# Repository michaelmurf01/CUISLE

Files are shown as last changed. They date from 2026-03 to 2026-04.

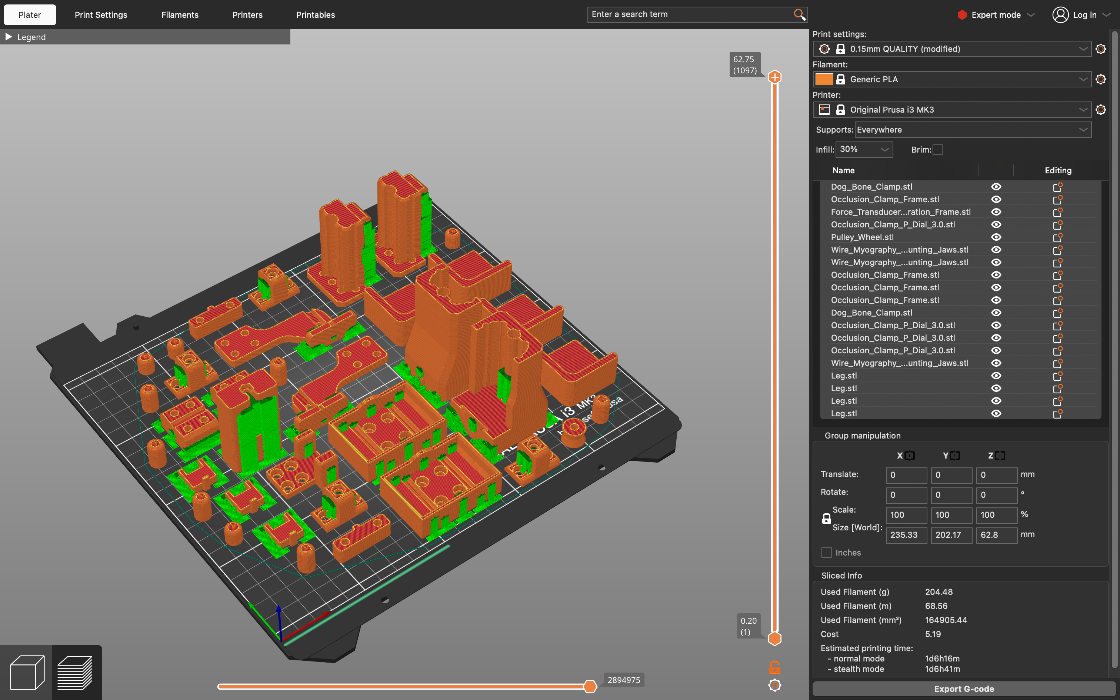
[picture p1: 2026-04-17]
Slicer_Images/All_Other_Parts_Slicer.png

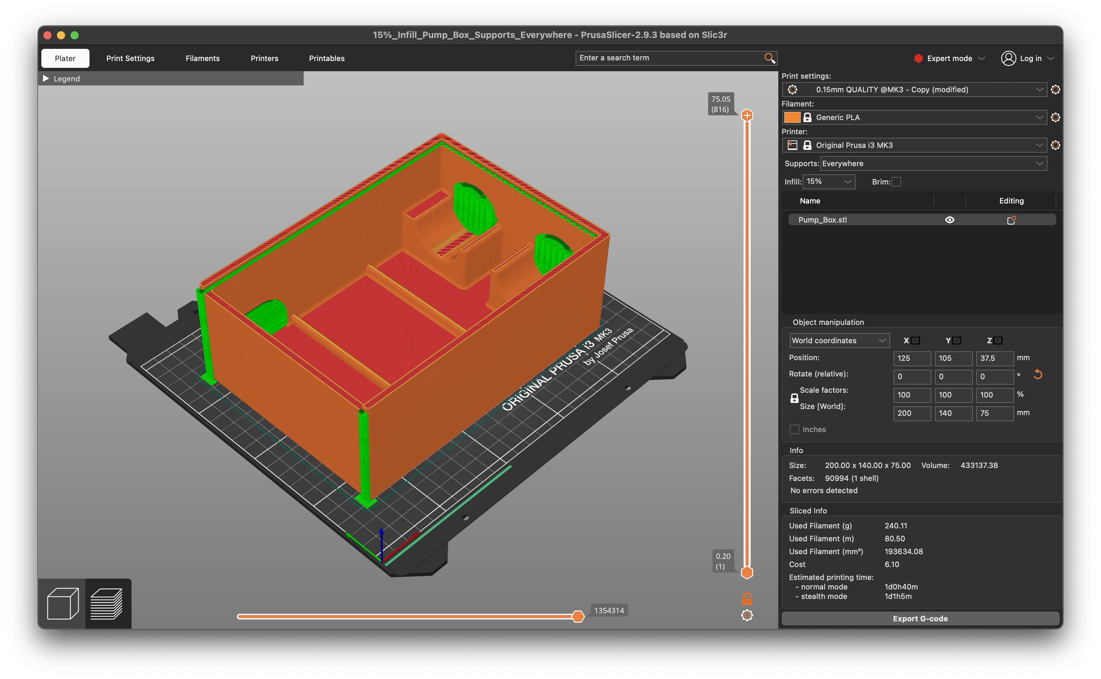
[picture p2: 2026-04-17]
Slicer_Images/Pump_Enclosure.png

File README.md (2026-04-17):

# CUISLE
### Cardiovascular Universal Instrument for Shared-source Low-cost Experimentation

*Cuisle (kwee-shla) — Irish for pulse/vein/artery*

---

A low-cost, open-source instrument for versatile vascular testing, developed at Trinity College Dublin. CUISLE supports four testing configurations — ring, wire myography, pressure myography and uniaxial — from a single multifunctional attachment, at a unit cost of €269.38 (inc. VAT, Ireland, March 2026).

---

## Repository Contents

| Type | Description |
|---|---|
| `/BOM` | Full Bill of Materials with component sources and costs |
| `/CAD` | All FDM printing files (.STL) for every printed module |
| `/Firmware` | Arduino IDE scripts for peristaltic pump control |

---

## Coming Soon
- 🔧 Step-by-step assembly and operating instructions

---

## Developed By
Michael William Murphy
supervised by Prof. Brooke Tornifoglio
Department of Mechanical, Manufacturing & Biomedical Engineering, Trinity College Dublin

---

## Licence
This project is open-source. If you use CUISLE in your research, please cite accordingly.

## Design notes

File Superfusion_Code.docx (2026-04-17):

SUPERFUSION CODE

#include <Servo.h>

// ─── CONFIG ───────────────────────────────────────────

// Direction: FORWARD or REVERSE

// Speed: 0 (fastest) to 89 (slowest, just before stop)

#define PUMP1_DIRECTION FORWARD // FORWARD

#define PUMP1_SPEED 20 // 20

#define PUMP2_DIRECTION FORWARD // FORWARD

#define PUMP2_SPEED 0 // 0

// ──────────────────────────────────────────────────────

#define FORWARD 1

#define REVERSE 0

Servo pump1;

Servo pump2;

#define PUMP1_PIN 9

#define PUMP2_PIN 10

int getAngle(int direction, int speed) {

// speed 0 = fastest, 89 = slowest

speed = constrain(speed, 0, 89);

if (direction == FORWARD) {

return speed; // 0–89 (0 = max forward)

} else {

return 180 - speed; // 180–91 (180 = max reverse)

}

}

void setup() {

pump1.attach(PUMP1_PIN);

pump2.attach(PUMP2_PIN);

pump1.write(90); // stop on startup

pump2.write(90);

delay(1000);

pump1.write(getAngle(PUMP1_DIRECTION, PUMP1_SPEED));

pump2.write(getAngle(PUMP2_DIRECTION, PUMP2_SPEED));

}

void loop() {

// Nothing needed — pumps run at fixed setting

}

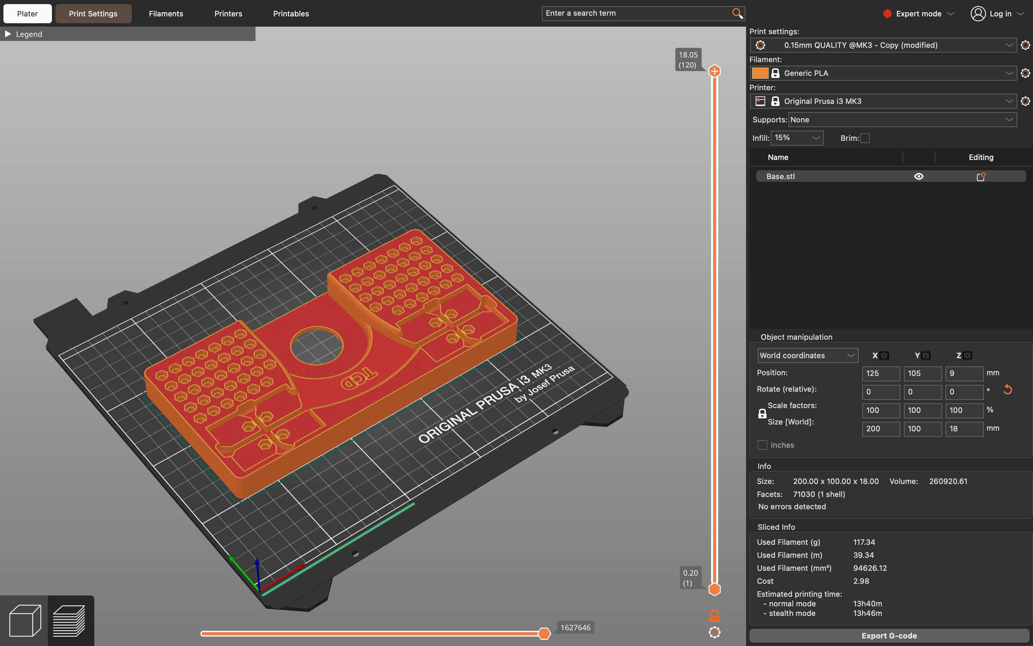
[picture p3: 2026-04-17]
Slicer_Images/Base_Slicer.png

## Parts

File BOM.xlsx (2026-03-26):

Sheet: Final BOM
Assembly Name | X
Assembly # | 1
Assembly Revision | 2026-04-10
Date of Approval | 2026-03-10
Total Cost (€) | 364.01 |  | * INC VAT, everything listed except Additional Items
Total Cost per Unit (€) | 269.38 |  | * INC VAT, everything listed except Additional Items
Item # | Lay Des. | Mfg. | Mfg. Des. | Mfg./Sup. Part # | Link | Qty | Units | Unit Cost (€) | Cost INC VAT (€) | Legend | Des. | Unit Cost (€) | Cost INC VAT (€)
Components |  |  |  |  |  |  |  |  |  | Components |  | 218.63 | 257.31
1 | PLA (1 kg spool) | Prusa | Prusament PLA Jet Black 1kg (NFC) | IDF: 17704|IDS: 3414 | https://www.prusa3d.com/product/prusament-pla-jet-black-1kg-nfc/ | 1 | 0.64 | 21.11 | 32.99 |  | Vessel Bath Components | 47.41 | 86.09
2 | Eraser | Milan | Milan 4 Pack Synthetic Rubber Erasers Blister Card | 420/0020 | https://www.easons.com/milan-4-pack-synthetic-rubber-erasers-blister-card-4200020 | 4 | 4 | 2.49 | 2.49
3 | Puck LED | OSRAM | OSRAM LED rechargeable furniture light DOT-IT, 1.8 cm, white touch dimmer | 10044291 | https://www.lights.ie/p/osram-led-rechargeable-furniture-light-dot-it-1-8-cm-white-touch-dimmer-10044291.html | 1 | 1 | 9.90 | 9.90
4 | M3 40 mm Pan Head Bolt (0.5 mm pitch) | McMaster-Carr | Passivated 18-8 Stainless Steel Pan Head Phillips Screws | 92000A136 | https://www.mcmaster.com/92000A136/ | 100 | 27 | 3.66 | 13.56
5 | M3 12 mm Hex Socket Bolt | McMaster-Carr | Alloy Steel Socket Head Screw, Zinc Plated, M3 x 0.5 mm Thread, 12 mm Long | 95263A146 | https://www.mcmaster.com/95263A146/ | 50 | 24 | 4.08 | 8.49
6 | M4 Hex Nut (Full) | McMaster-Carr | Zinc-Plated Steel Hex Nut, Medium-Strength, ISO Class 8, M3 x 0.5 mm Thread Size | 90591A250 | https://www.mcmaster.com/90591A250/ | 100 | 52 | 1.52 | 2.92
7 | M3 Washer | McMaster-Carr | 18-8 Stainless Steel General Purpose Washer | 93475A230 | https://www.mcmaster.com/93475A230/ | 100 | 6 | 0.22 | 3.73
8 | Elastic Band Assortment | Tiger | Tiger Essential Rubber Bands Coloured - 100g | 209/7818 | https://www.easons.com/tiger-essential-rubber-bands-coloured-100g-2097818 | 1 | 1 | 4.00 | 4.00
9 | Extension and Compression Spring | RS | Rolson 61298 150 pc Spring Assortment Hardware Pin, Silver | B000QF7JTO | https://www.amazon.ie/Rolson-61298-Spring-Assortment-Hardware/dp/B000QF7JTO | 150 | 8 | 0.43 | 8.01
10 | Microcontroller | Arduino | Arduino Uno REV3 | A000066 | https://www.amazon.ie/Arduino-Uno-REV3-A000066-Microcontroller/dp/B008GRTSV6 | 1 | 1 | 28.85 | 28.85 |  | Pressure Components | 92.15 | 92.15
11 | Breadboard | Velleman | Velleman VTBB3 High-Quality 400 Holes Breadboard, Multi-Colour | VTBB3 | https://www.amazon.ie/Velleman-VTBB3-High-Quality-Breadboard-Multi-Colour/dp/B077ZKDQKW | 1 | 1 | 3.49 | 3.49
12 | Peristaltic Pump | DFRobot | Gravity Digital Peristaltic Pump, for Arduino, Raspberry Pi & micro:bit Board | DFR0523 | https://ie.farnell.com/dfrobot/dfr0523/gravity-digital-peristaltic-pump/dp/3517940?CMP=KNC-GIE-GEN-SKU-OPTMYZR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 | 2 | 2 | 23.72 | 23.72
13 | Jumper Wire Kit | Haochen | 560 PcsJumper Wire Kit | B07FBCJ7GK | https://www.amazon.ie/PcsJumper-Breadboard-Preformed-Solderless-Prototyping/dp/B07FBCJ7GK | 1 | 1 | 7.40 | 7.40
14 | Barrel Jack to Pin Adaptor | DFRobot | DC Power Connector, Jack, Screw | FIT0151 | https://ie.farnell.com/dfrobot/fit0151/dc-barrel-adapter-jack-5-5x2-1mm/dp/4308210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 | 1 | 1 | 2.02 | 2.02
15 | Power Adapter | Mean Well | MEAN WELL 30W Power Brick AC/DC Adapter 5V dc Output, 6A Output | GST60A05-P1J | https://int.rsdelivers.com/product/mean-well/gst60a05-p1j/mean-well-30w-power-brick-ac/dc-adapter-5v-dc-output-6a-output/8808391 | 1 | 1 | 23.73 | 23.73
16 | Power Cable | Pro Elec | LEAD UK PLUG TO IEC C13 BLACK 0.5M | PELB1202 | https://ie.farnell.com/pro-elec/pelb1202/lead-uk-plug-to-iec-c13-black/dp/4690705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 | 1 | 1 | 2.94 | 2.94
35 | Cooking Pot | GSW | GSW Stahlwaren Stock Pot with Glass Lid, Stainless Steel, Polished Finish, 5 Litre, 20x18cm, Silver/Clear | 990189 | https://www.amazon.ie/GSW-Stahlwaren-Stainless-Polished-20x18cm/dp/B01LXV1FI1?s=home | 1 | 1 | 21.99 | 21.99 |  | Temperature Components | 79.07 | 79.07
34 | Immersion Circulator | Wancle | Wancle Sous Vide Sous Vide Machine Precision Cooker 1100W Sous Vide Cooker IPX7 Waterproof Immersion Circulator With Reservation Function Easy to Store (Black) | M820 | https://www.amazon.ie/Wancle-Precision-Waterproof-Circulator-Reservation/dp/B094921FYY?th=1 | 1 | 1 | 52.09 | 52.09
36 | Thermometer | Europapa | EUROPAPA Digital Fever Thermometer for Babies, Children and Adults, Thermometer for Oral, Axillary or Rectal Use, Waterproof with Fever Alarm (Purple) | 80189 | https://www.amazon.ie/EUROPAPA-Thermometer-Children-Axillary-Waterproof/dp/B0CBP1F19R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 | 1 | 1 | 4.99 | 4.99
Consumables |  |  |  |  |  |  |  |  |  | Consumables |  | 36.63 | 92.58
17 | Dispensing Tip (30 Gauge) | Kahnetics | Kahnetics Purple Straight Dispensing Tip, 30 Gauge | KDS3012P | https://ie.rs-online.com/web/p/dispensing-tips/4003902 | 50 | 2 | 1.79 | 44.71 |  | Construction Consumables | 11.48 | 67.43
18 | Leur Lock | AIEX | 30pcs Syringe Adapter, Clear Female Luer Lock 1/8" Luer Lock Connector Kit to Syringe Coupler Adapter (3.2mm) | B13246 | https://www.amazon.ie/Syringe-Adapter-Female-Connector-Coupler/dp/B0BMFJSJP1?adgrpid=184449477008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 | 30 | 2 | 0.38 | 5.63
19 | Garden Wire | Tenn Well | 100m Green Garden Wire, Flexible Plant Wire Twist Ties with Cutter for Gardening Climbing Plants, Vines, Shrubs and Flowers | B08ZC5G8V2 | https://www.amazon.ie/tenn-well-Flexible-Gardening-Climbing/dp/B08ZC5G8V2?adgrpid=174819309733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 | 1 | 1 | 8.56 | 8.56
20 | Staple (no. 16 or 24/6) | Q-Connect | Q-Connect 24/6 Metal Precision Engineered Staples (1000 Pack) | B002MXE9JQ | https://www.amazon.ie/Q-Connect-Metal-Precision-Engineered-Staples/dp/B002MXE9JQ?adgrpid=175589183035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 | 1000 | 3 | 0.00291 | 0.97
21 | Petri Dish (60 mm D) | Melgo | 10 Pcs Plastic Petri Dish, Sterile Bacterial Culture Dish, Laboratory Plant Cell Tissue Petri Dish Accessories for Lab Supplies, School Science Equipment (Plastic-60mm-10Pcs) | B0BB9RLV52 | https://www.amazon.ie/Bacterial-Laboratory-Accessories-Equipment-Plastic-60mm-10Pcs/dp/B0BB9RLV52 | 10 | 1 | 0.76 | 7.56
22 | Thread | Korbond | Korbond CORE Mix Polyester Thread Selection by Korbond-12 x 32m spools – 10 Colours – 384 metres – Hand and Machine Sewing, Repairs, Crafting, White | B007MCRA84 | https://www.amazon.ie/Korbond-Polyester-Thread-Selection-Korbond-12/dp/B007MCRA84?adgrpid=174959828396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 | 1 | 1 | 2.38 | 2.38 |  | Testing Consumables | 25.15 | 25.15
23 | Silicone Lubricant | PETEC | PETEC Silicone spray, 500 ml, 70850 | 70850 | https://www.amazon.ie/PETEC-Silicone-spray-500-70850/dp/B018461HL2?adgrpid=173616327334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 | 1 | 1 | 6.98 | 6.98
24 | Super Glue | Loctite | Loctite 950014 Superglue Gel | 950014 | https://www.amazon.ie/Loctite-2056169-950014-Superglue-Gel/dp/B00U1OPL8Q | 1 | 1 | 4.49 | 4.49
25 | Hook and Loop Fastener | Velcro | VELCRO® Brand | Stick On Tape | Cut-to-Length Strong Hook & Loop Self Adhesive Sticky Tape Perfect for Room Décor & Home, Office, Garage Use | Black | 20mm x 1m | N/A | https://www.amazon.ie/VELCRO®-Brand-Length-Adhesive-Perfect/dp/B0017S83PI | 1 | 1 | 4.39 | 4.39
26 | Nail Polish Remover | Cutex | Cutex Nourishing Nail Polish Remover 200 ml | 7240886000 | https://www.amazon.ie/Cutex-Nourishing-Nail-Polish-Remover/dp/B06XB9Q6ZX | 1 | 1 | 2.99 | 2.99
27 | Adhesiive Putty | Bostik | BOSTIK Blu Tack Light Blue - Permanent Plastic Reusable Adhesive, Reliable and Removable Fixation, 46 g | ‎5048700002 | https://www.amazon.ie/BOSTIK-Blu-Tack-Light-Blue/dp/B0015M12G8 | 1 | 1 | 3.92 | 3.92
Equipment |  |  |  |  |  |  |  |  |  | Equipment |  | 14.12 | 14.12
28 | M3 Alan Key | Matador | Matador 0440 0030 Allen Key Short, Hexagonal, 3 mm | 0440 0030 | https://www.amazon.ie/Matador-0440-0030-Allen-Hexagonal/dp/B00PLYHWGU | 1 | 1 | 1.72 | 1.72 |  | Construction Tools | 8.16 | 8.16
29 | Weighing Scales | Salter | Salter 1066 BKDR15 Arc Kitchen Scale – Digital Food Weighing Scales For Precise Cooking/Baking, Slim Platform for Compact Storage, Add & Weigh/Tare Function, 3kg Capacity, Battery Included, Black | 1066 BKDR15 | https://www.amazon.ie/gp/aw/d/B00140VYEG/?aaxitk=7cbafefce3d7e709439bdd2409773615&hsa_cr_id=0&aref=L250n6CW7a | 1 | 1 | 6.44 | 6.44
30 | Wire Strippers | Velleman | Velleman VTSTRIP1E Adjustable Wire Stripper/Cutter, Multi-Colour | VTSTRIP1E | https://www.amazon.ie/Velleman-VTSTRIP1E-Adjustable-Stripper-Multi-Colour/dp/B003U3RB8S?s=industrial | 1 | 1 | 5.96 | 5.96 |  | Testing Tool | 5.96 | 5.96
Additional Items |  |  |  |  |  |  |  |  |  | Additional Items |  | 581.97 | 581.97
31 | Brightfield Microscope | PalliPartners | Microscopes for Kids Students Adults, 100X-2000X Powerful Biological Microscopes for Home Education,with Microscope Slides Set, Phone Adapter | SMUK-XWJ-01 | https://www.amazon.ie/Microscopes-100X-2000X-Biological-Education-Microscope/dp/B0FHL13BF7 | 1 | 1 | 81.55 | 81.55 |  | Additional Items | 581.97 | 581.97
32 | 3D FDM Printer | Bambu Lab | Bambu Lab A1 3D Printer | N/A | https://eu.store.bambulab.com/products/a1?id=599117150694776840 | 1 | 1 | 285.71 | 285.71
33 | Laptop | HP | HP Chromebook 15.6" | Intel Celeron N4500 Processor | 4 GB RAM | 128 GB eMMC | Intel UHD Graphics | HD Display | Up to 11 hours battery | Chrome OS | Dual Speakers | Mineral Silver | 15a-na0005sa | 9V2S8EA#ABU | https://www.amazon.ie/HP-Chromebook-Processor-Graphics-15a-na0005sa/dp/B0CRHC4GTZ | 1 | 1 | 214.71 | 214.71

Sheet: Analysis
 | Prototype (Unit) | Prototype (Total)
Vessel Bath Components | 47.41 | 86.09
Pressure Components | 92.15 | 92.15
Temperature Components | 79.07 | 79.07
Construction Consumables | 11.48 | 67.43
Testing Consumables | 25.15 | 25.15
Construction Tools | 8.16 | 8.16
Testing Tool | 5.96 | 5.96
 | Prototype (Unit) | Prototype (Total) | HemoLens (Unit) | HemoLens (Total) | VasoTracker 1 (Unit) | VasoTracker 2 (Unit) | MDE IS-05 Wire Myograph (Unit) | LSI 2-Channel Self-Heated Wire Myograph Package (Unit) | DMT Pressure Myograph System - 112PP (Unit)
Components | 218.63 | 257.31 | 642.35 | 767.50 | 1676.27 | 4501.64 | 9560.00 | 17184.73 | 45850.00
Consumables | 36.63 | 92.58 | 2.64 | 65.88 | 0.00 | 163.93 | 0.00 | 0.00 | 0.00
Equipment | 14.12 | 14.12 | 0.00 | 0.00 | 0.00 | 0.00 | 0.00 | 0.00 | 0.00
Total | 269.38 | 364.01 | 644.99 | 833.38 | 1676.27 | 4665.57 | 9560.00 | 17184.73 | 45850.00

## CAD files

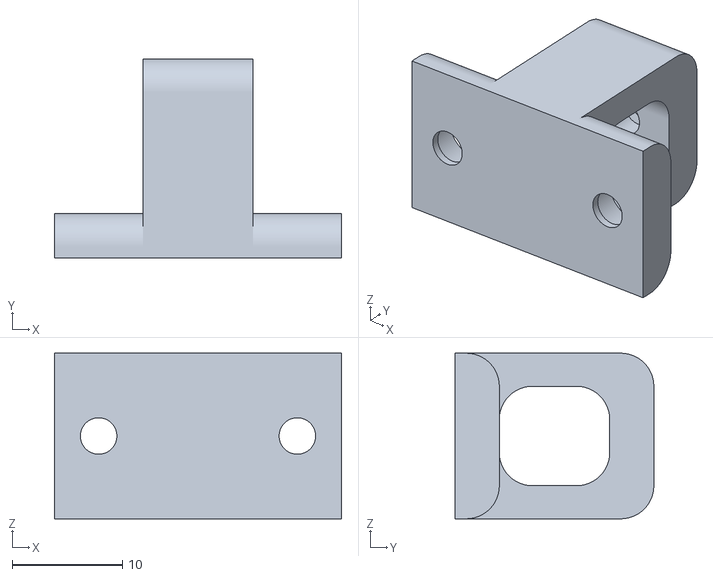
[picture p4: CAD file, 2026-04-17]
STL_Parts/Occlusion_Clamp_Frame.stl
26.0 x 18.0 x 15.0

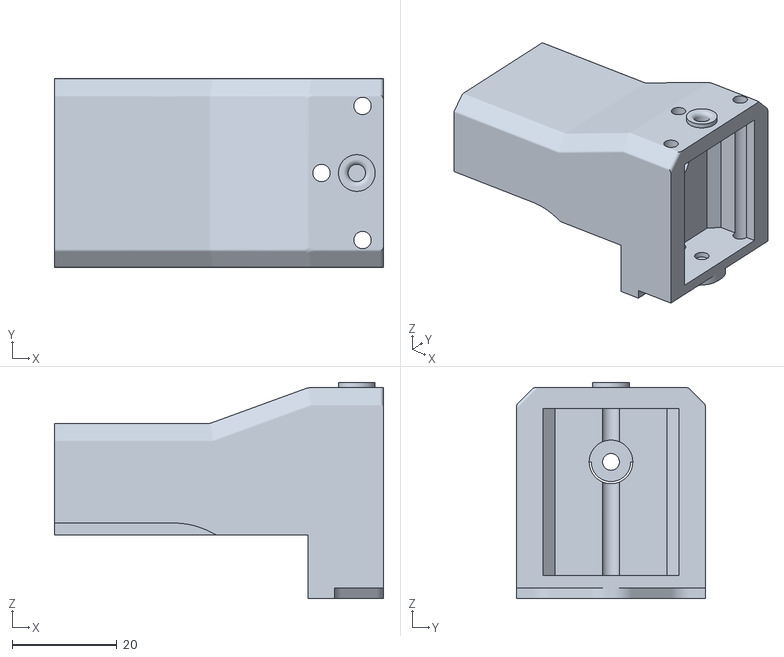
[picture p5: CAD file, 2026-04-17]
STL_Parts/MM_Top.stl
62.8 x 36.0 x 41.2

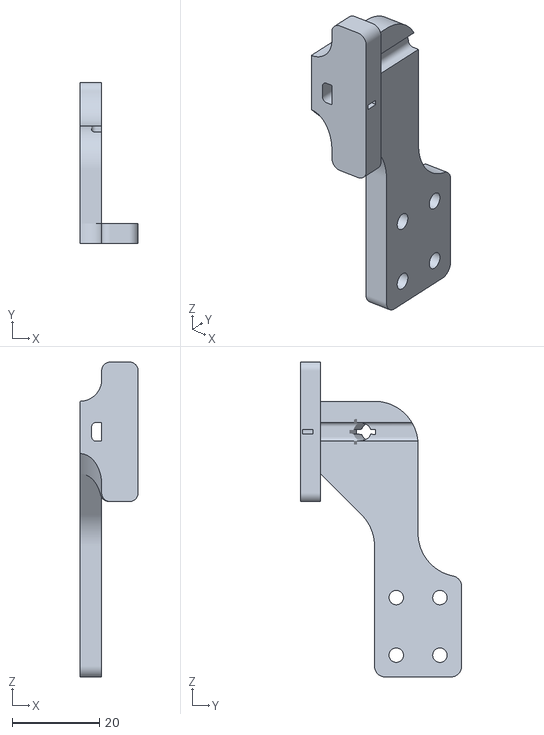
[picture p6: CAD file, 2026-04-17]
STL_Parts/Attachment_Mirror.stl
13.4 x 37.0 x 72.2

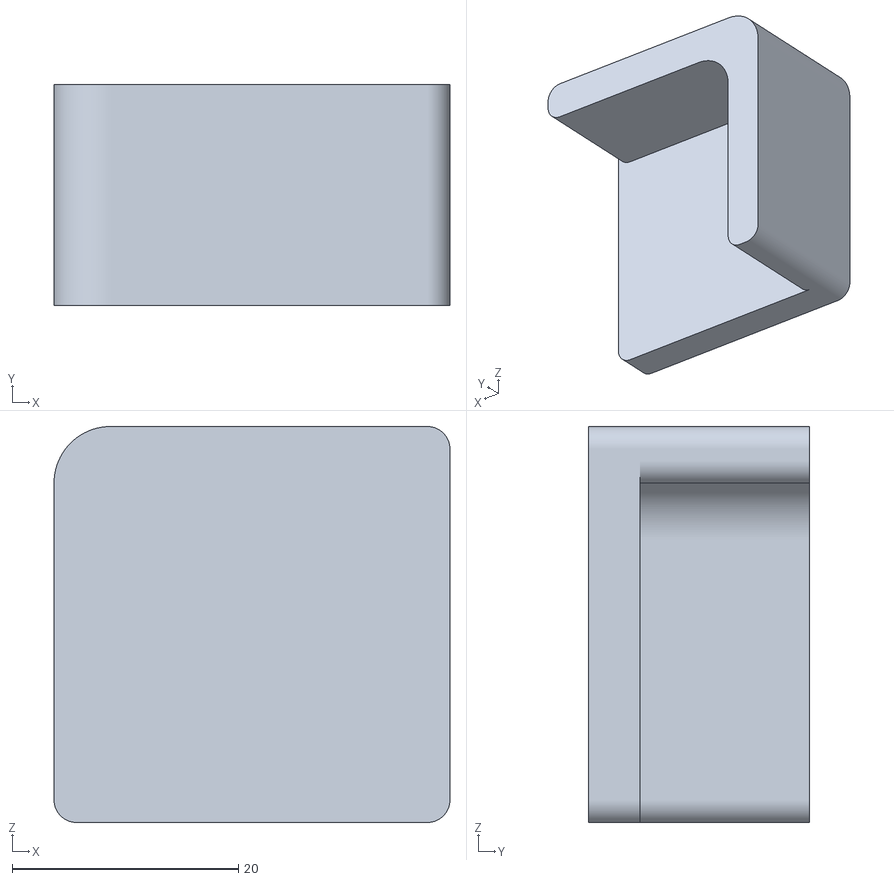
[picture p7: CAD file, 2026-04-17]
STL_Parts/Leg.stl
35.0 x 19.5 x 35.0

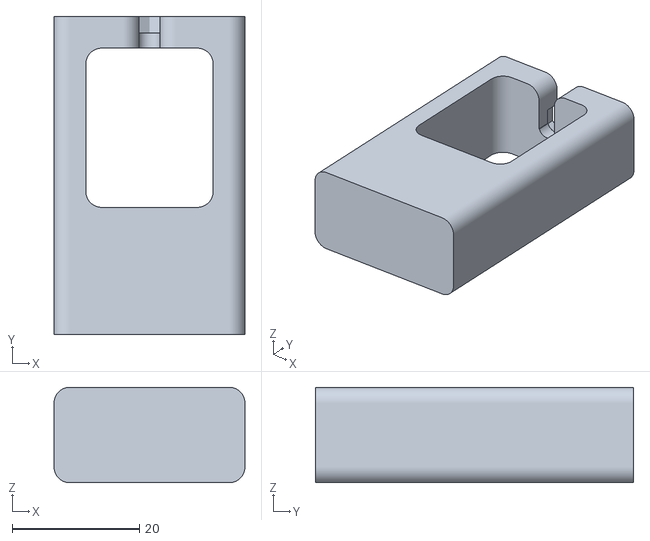
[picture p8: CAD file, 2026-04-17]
STL_Parts/Glue_Support.stl
30.0 x 50.0 x 15.0

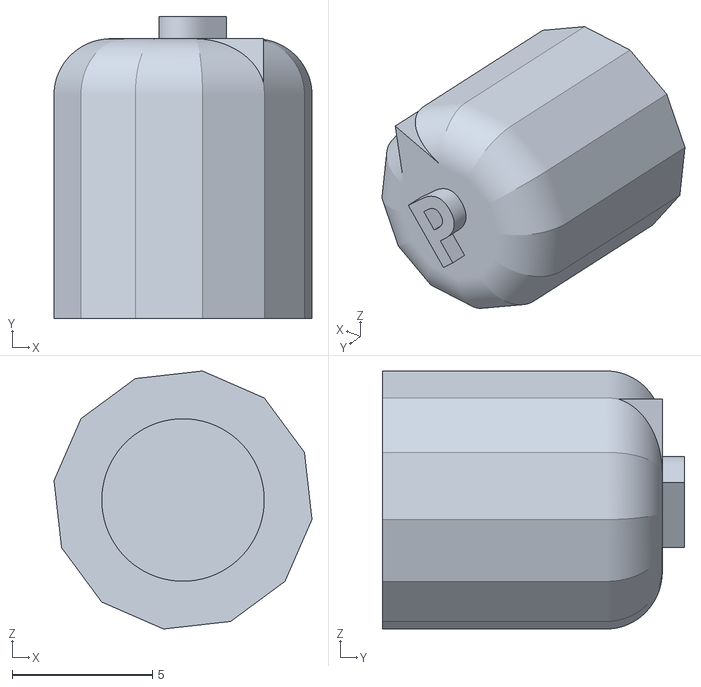
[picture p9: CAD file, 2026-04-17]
STL_Parts/Occlusion_Clamp_P_Dial_3.0.stl
9.21 x 10.8 x 9.21

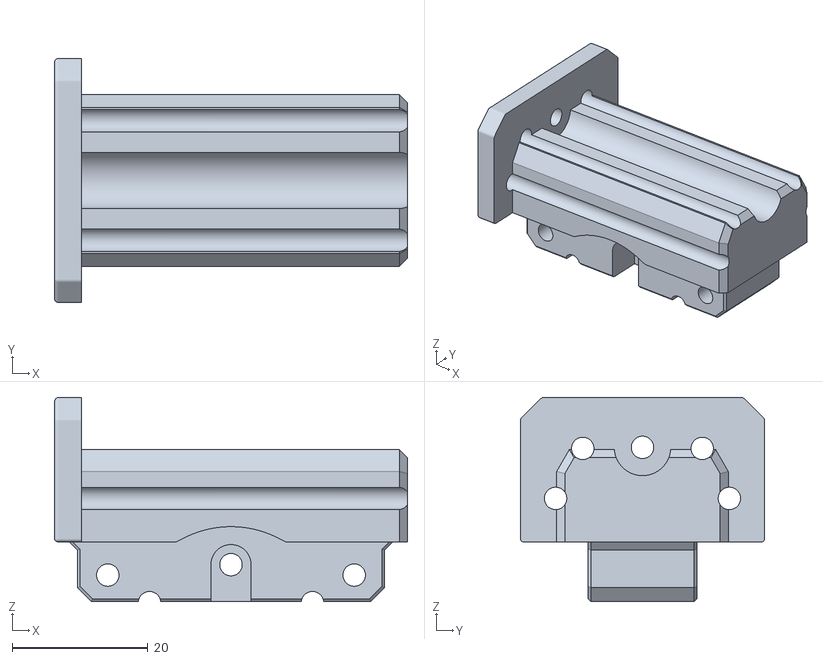
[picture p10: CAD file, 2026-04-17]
STL_Parts/MM_Middle.stl
52.0 x 36.0 x 30.1

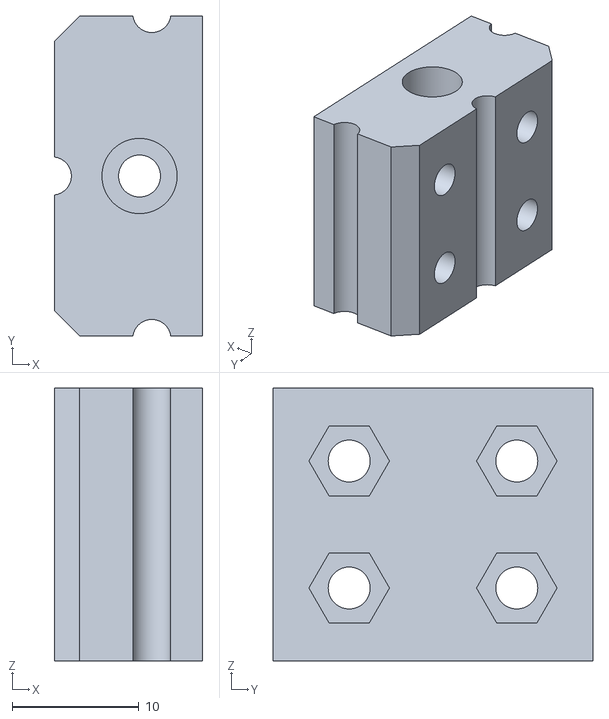
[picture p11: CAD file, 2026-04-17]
STL_Parts/MM_Slider.stl
11.7 x 25.2 x 21.5

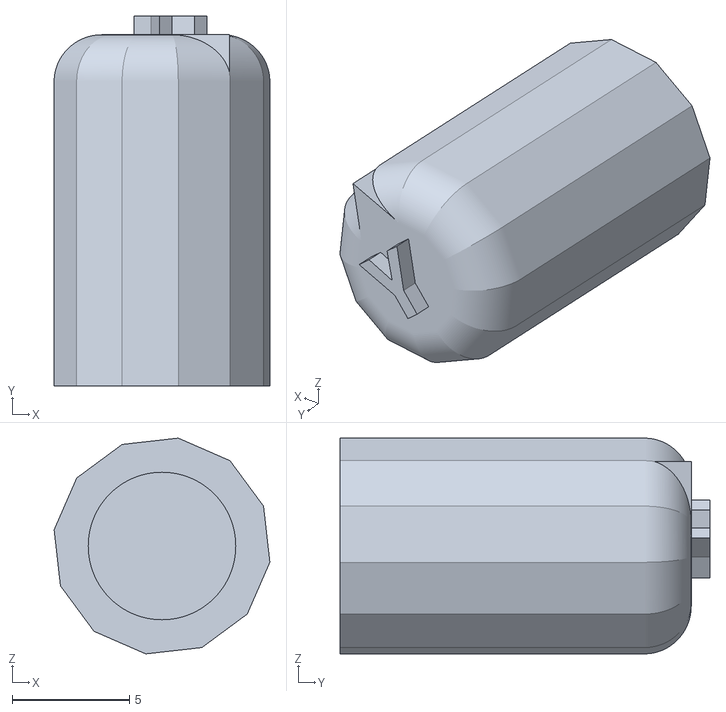
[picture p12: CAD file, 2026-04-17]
STL_Parts/MM_Y_Dial_3.0.stl
9.21 x 15.8 x 9.21

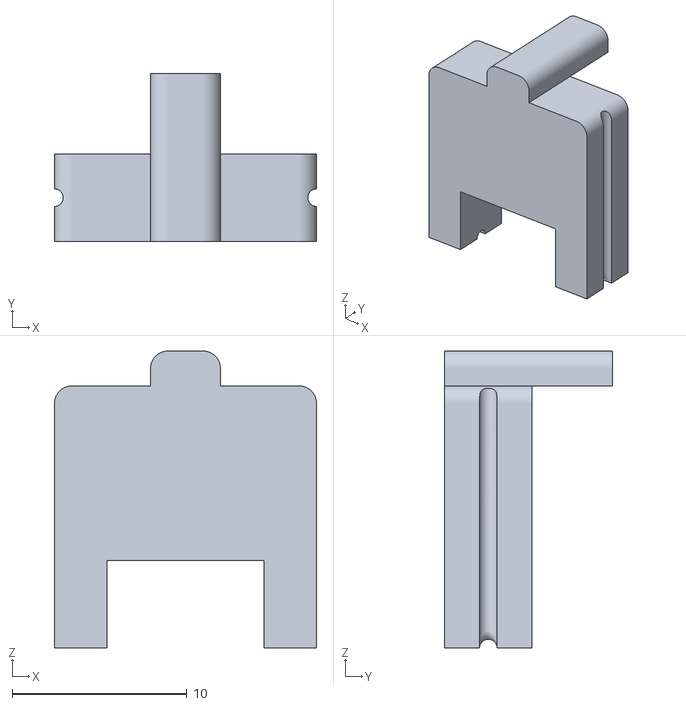
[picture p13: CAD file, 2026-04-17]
STL_Parts/Wire_Myography_Mounting_Jaws.stl
15.0 x 9.60 x 17.0

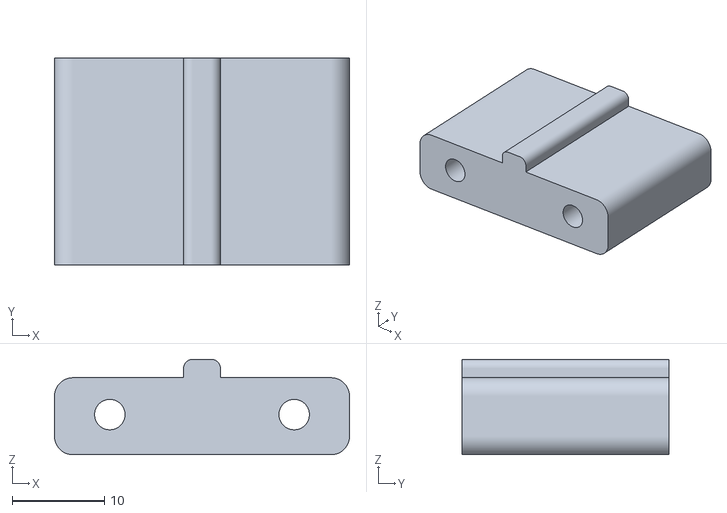
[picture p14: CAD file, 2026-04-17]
STL_Parts/Dog_Bone_Clamp.stl
32.0 x 22.4 x 10.4

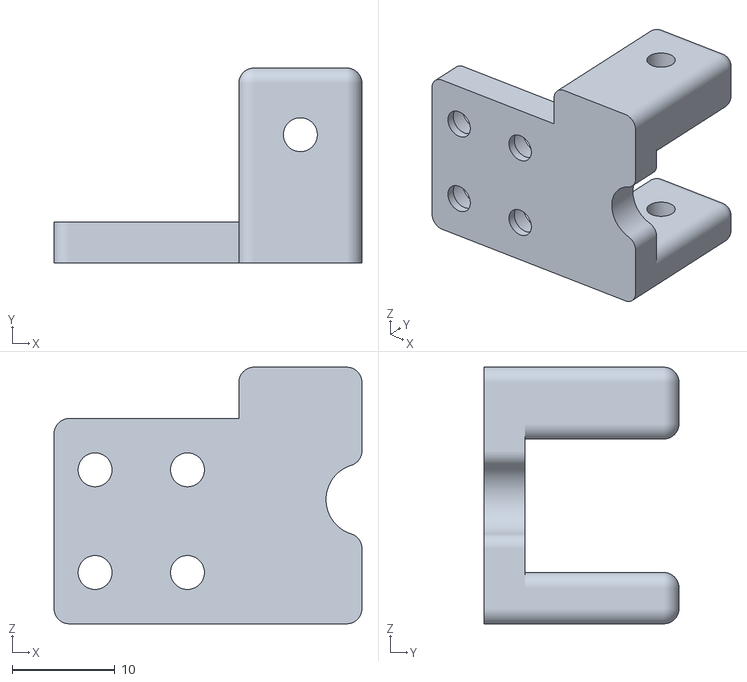
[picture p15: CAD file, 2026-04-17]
STL_Parts/Force_Transducer_Calibration_Frame.stl
30.0 x 19.0 x 25.0

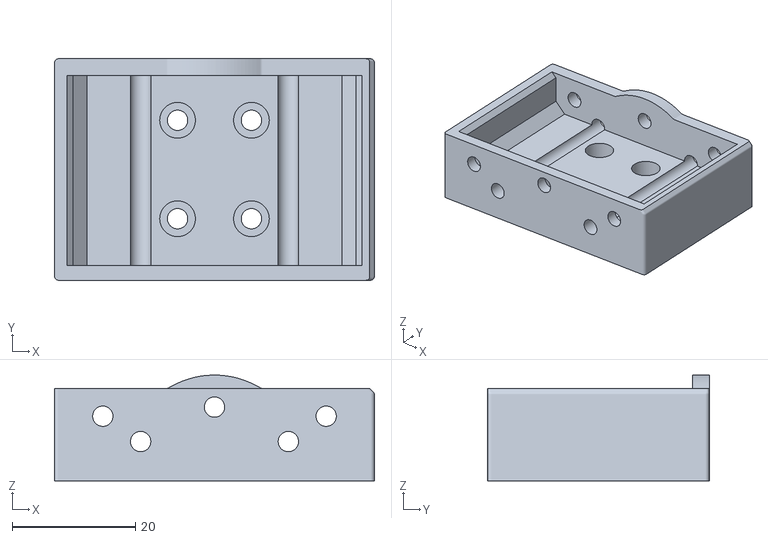
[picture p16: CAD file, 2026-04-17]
STL_Parts/MM_Base.stl
52.0 x 36.0 x 17.2

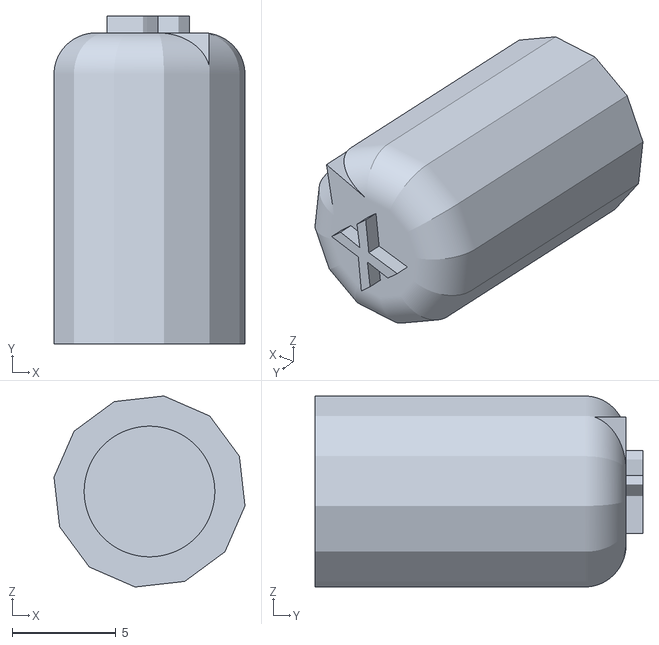
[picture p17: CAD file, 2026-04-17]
STL_Parts/MM_X_Dial_3.0.stl
9.21 x 15.8 x 9.21

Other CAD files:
STL_Parts/MM_Top_Mirror.stl
STL_Parts/MM_Middle_Mirrored.stl
STL_Parts/Pulley_Wheel.stl
STL_Parts/Attachment.stl
STL_Parts/Base.stl
STL_Parts/MM_Z_Dial_3.0.stl
